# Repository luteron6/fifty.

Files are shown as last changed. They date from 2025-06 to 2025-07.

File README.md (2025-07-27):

# fifty.


This is my take on a minimalist 50% keyboard optimized for commandlines. I created it to solve a problem controlling the computer in my travel van. There's a monitor and computer mounted in the vehicle, but when I'm using it, there's no good spot to put the keyboard. It could go on my lap, but it's huge (~90% keyboard). And there's no spot for a mouse or touchpad. This solves both these problems. At first the goal was to create a 40% keyboard with a touchpad, but it ended up being a 50% keyboard (48 keys) with a round touchpad and right/left mouse buttons. It uses MX Brown switches, a Cirque trackpad, all powered by a Waveshare RP2040-Plus:
<br><br>

It's made to run this keymap:
<br><br>

## CAD
The case is stored in the /CAD folder, both the STL files and the STEP file. Meant to be 3D printed. Everything bolts together with M2 screws and threaded inserts. Also has rubber feet on the bottom.



## PCB
The PCB gerbers and source files are stored in the /PCB folder. I made it in KiCAD:


It needs:
* MX-Style Switches (50)
* SOD-123 Diodes (50)
* Cirque 40mm Trackpad
* 4.7k ohm Resistors (2)
* RP2040-Plus
* Screw-In Stabilizers (1x 2u and 1x 6.25u)

## Code
I made the code in QMK. Source files are in the /Code folder. Still a work in progress, but QMK MSYS can build it, so I put the .uf2 file in the folder. I might still change the layout, but currently it's documented above.

## BOM
| Item | QTY Needed | QTY Purchased | Price | Description | Link |
|---|---|---|---|---|---|
| MX Brown Switches | 50 | 70 | $24.99  | Keyboard Switches! | [link](https://www.amazon.com/Pre-lubed-Switches-Mechanical-Keyboard-Pcs-5pin/dp/B0CKTJLCDB) |
| Cirque Trackpad | 1 | 1 | $27.00  | Trackpad Module | [link](https://shop.beekeeb.com/product/40mm-cirque-glidepoint-circle-trackpad-module-diy-kit-for-split-mechanical-keyboard/) |
| RP2040-Plus | 1 | 1 | $6.99 | Microcontroller | [link](https://www.waveshare.com/rp2040-plus.htm?sku=23503) |
| USB-C Connector | 1 | 1 | $12.99  | USB-C adapter | [link](https://www.amazon.com/Tciogrxp-Magnetic-Connector-Compatible-Thunderbolt/dp/B0DFM1B3DK/) |
| Stabilizers | 1 | 1 | $16.98  | Screw-In Stabilizers | [link](https://www.amazon.com/DUROCK-Stabilizers-Translucent-Keyboard-Mechanical/dp/B0B2RVN19F/) |
| Diodes | 50 | 100 | $6.99 | SOD-123 1N4148W SMD Diodes | [link](https://www.amazon.com/100-Pieces-1N4148W-Switching-High-Speed/dp/B079KJX5J9/) |
| Rubber Feet | 4 | 12 | $5.99 | Rubber Silicone Feet | [link](https://www.amazon.com/Pack-Rubber-Silicone-Feet-Diameter/dp/B0927HC2TD/) |
| Keycaps | 1 | 1 | $14.69  | Low Profile Keycaps! | [link](https://www.amazon.com/XVX-Profile-Keycaps-Keyboard-Mechanical/dp/B0C1B6STX4) |
| Resistors | 2 | 3250 | $7.99 | SMD resistors | [link](https://www.amazon.com/Yobett-3250PCS-Resistor-Tolerance-Resistors/dp/B0BZGQ8136/) |
| PCB (ordered from JLCPCB) | 1 | 5 | $15.00  | | |
| Sales Tax | | | $10.82  | | |
| Shipping | | | $30.00  | JLCPCB Shipping | |
| Shipping | | | $15.00  | beekeeb Shipping | |
| | | | | | |
| TOTAL | | | $195.43 | | |

made with love by a hack clubber

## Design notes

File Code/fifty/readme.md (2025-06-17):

# fifty

fifty

*A short description of the keyboard/project*

* Keyboard Maintainer: [luteron6](https://github.com/luteron6)
* Hardware Supported: *The PCBs, controllers supported*
* Hardware Availability: *Links to where you can find this hardware*

Make example for this keyboard (after setting up your build environment):

    make fifty:default

Flashing example for this keyboard:

    make fifty:default:flash

See the [build environment setup](https://docs.qmk.fm/#/getting_started_build_tools) and the [make instructions](https://docs.qmk.fm/#/getting_started_make_guide) for more information. Brand new to QMK? Start with our [Complete Newbs Guide](https://docs.qmk.fm/#/newbs).

## Bootloader

Enter the bootloader in 3 ways:

* **Bootmagic reset**: Hold down the key at (0,0) in the matrix (usually the top left key or Escape) and plug in the keyboard
* **Physical reset button**: Briefly press the button on the back of the PCB - some may have pads you must short instead
* **Keycode in layout**: Press the key mapped to `QK_BOOT` if it is available

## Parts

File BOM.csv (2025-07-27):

Item | QTY Needed | QTY Purchased | Price | Description | Link
MX Brown Switches | 50 | 65 | $15.00 | Keyboard Switches! | https://www.amazon.com/Gateron-KS-9-Mechanical-Type-Switch/dp/B07X3VLF89/
Cirque Trackpad | 1 | 1 | $27.00 | Trackpad Module | https://shop.beekeeb.com/product/40mm-cirque-glidepoint-circle-trackpad-module-diy-kit-for-split-mechanical-keyboard/
RP2040-Plus | 1 | 1 | $6.99 | Microcontroller | https://www.waveshare.com/rp2040-plus.htm?sku=23503
Stabilizers | 1 | 1 | $16.98 | Screw-In Stabilizers | https://www.amazon.com/DUROCK-Stabilizers-Translucent-Keyboard-Mechanical/dp/B0B2RVN19F/
Diodes | 50 | 100 | $6.99 | SOD-123 1N4148W SMD Diodes | https://www.amazon.com/100-Pieces-1N4148W-Switching-High-Speed/dp/B079KJX5J9/
Rubber Feet | 4 | 12 | $5.99 | Rubber Silicone Feet | https://www.amazon.com/Pack-Rubber-Silicone-Feet-Diameter/dp/B0927HC2TD/
Keycaps | 1 | 1 | $14.69 | Low Profile Keycaps! | https://www.amazon.com/XVX-Profile-Keycaps-Keyboard-Mechanical/dp/B0C1B6STX4
Resistors | 2 | 3250 | $7.99 | SMD resistors | https://www.amazon.com/Yobett-3250PCS-Resistor-Tolerance-Resistors/dp/B0BZGQ8136/
PCB (ordered from JLCPCB) | 1 | 5 | $15.00
Sales Tax |  |  | $10.82
Shipping |  |  | $30.00 | JLCPCB Shipping
Shipping |  |  | $15.00 | beekeeb Shipping
TOTAL |  |  | $172.45
 | 0.357142857

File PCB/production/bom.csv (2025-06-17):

Designator | Footprint | Quantity | Value | LCSC Part #
D1, D10, D11, D12, D13, D14, D15, D16, D17, D18, D19, D2, D20, D21, D22, D23, D24, D25, D26, D27, D28, D29, D3, D30, D31, D32, D33, D34, D35, D36, D37, D38, D39, D4, D40, D42, D43, D44, D45, D46, D5, D51, D52, D53, D54, D55, D6, D7, D8, D9 | D_SOD-123 | 50 | D
J1 | Touchpad | 1 | TOUCHPAD
R1, R2 | 0402 | 2 | Resistor
SW1, SW43, SW44, SW51 | MX_PCB_1.25u | 4 | SW_Push_45deg
SW10, SW11, SW12, SW13, SW14, SW16, SW17, SW18, SW19, SW2, SW20, SW21, SW22, SW23, SW24, SW25, SW26, SW28, SW3, SW30, SW31, SW32, SW33, SW34, SW35, SW36, SW37, SW38, SW39, SW4, SW42, SW45, SW5, SW52, SW53, SW54, SW55, SW6, SW7, SW8, SW9 | MX_PCB_1.00u | 41 | SW_Push_45deg
SW15 | MX_PCB_1.50u | 1 | SW_Push_45deg
SW27, SW40 | MX_PCB_1.75u | 2 | SW_Push_45deg
SW29 | MX_PCB_2.00u | 1 | SW_Push_45deg
SW46 | MX_PCB_6.25u | 1 | SW_Push_45deg
U1 | Raspberry_Pi_Pico | 1 | Raspberry_Pi_RP2040-PLUS

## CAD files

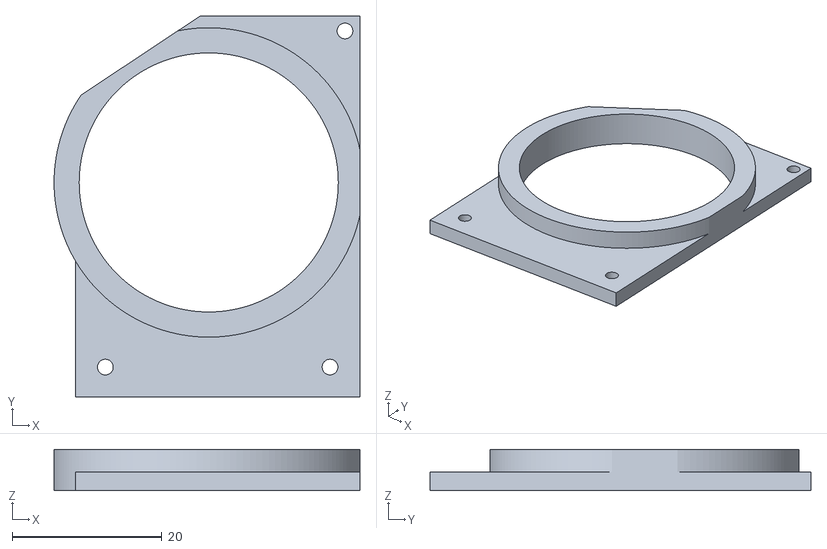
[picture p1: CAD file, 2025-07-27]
CAD/trackpad-holder.stl
40.9 x 50.9 x 5.50

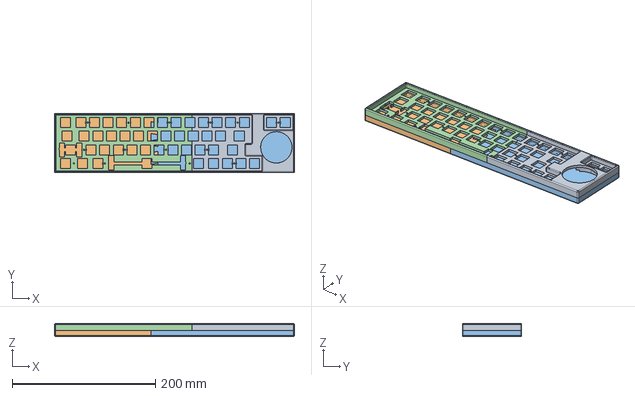
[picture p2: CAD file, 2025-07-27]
CAD/fifty.step
335.4 x 83.0 x 18.1 mm

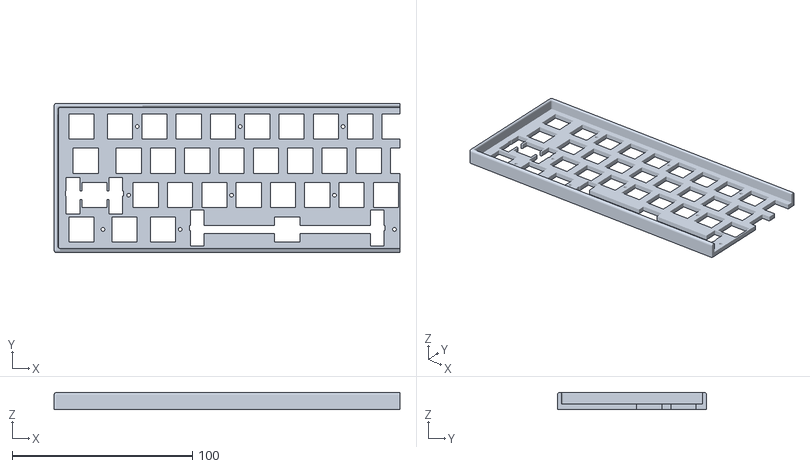
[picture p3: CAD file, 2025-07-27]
CAD/top-left.stl
192.2 x 83.0 x 9.60

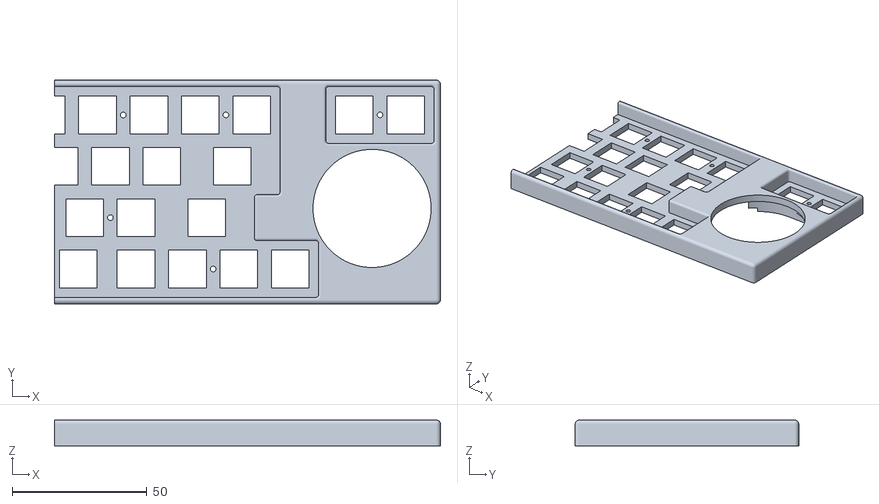
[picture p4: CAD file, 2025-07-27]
CAD/top-right.stl
143.2 x 83.0 x 9.60

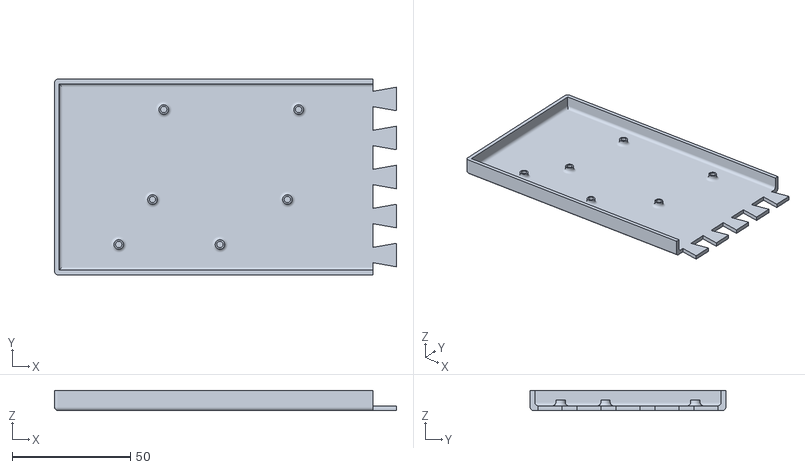
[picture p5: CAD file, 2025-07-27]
CAD/bottom-left.stl
144.8 x 83.0 x 8.50

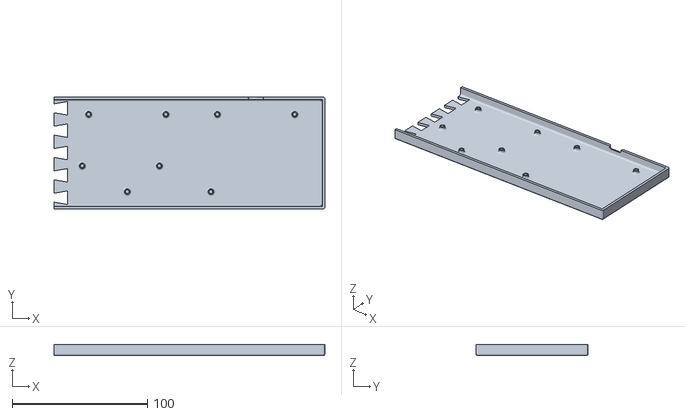
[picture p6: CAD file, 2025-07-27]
CAD/bottom-right.stl
200.4 x 83.0 x 8.50

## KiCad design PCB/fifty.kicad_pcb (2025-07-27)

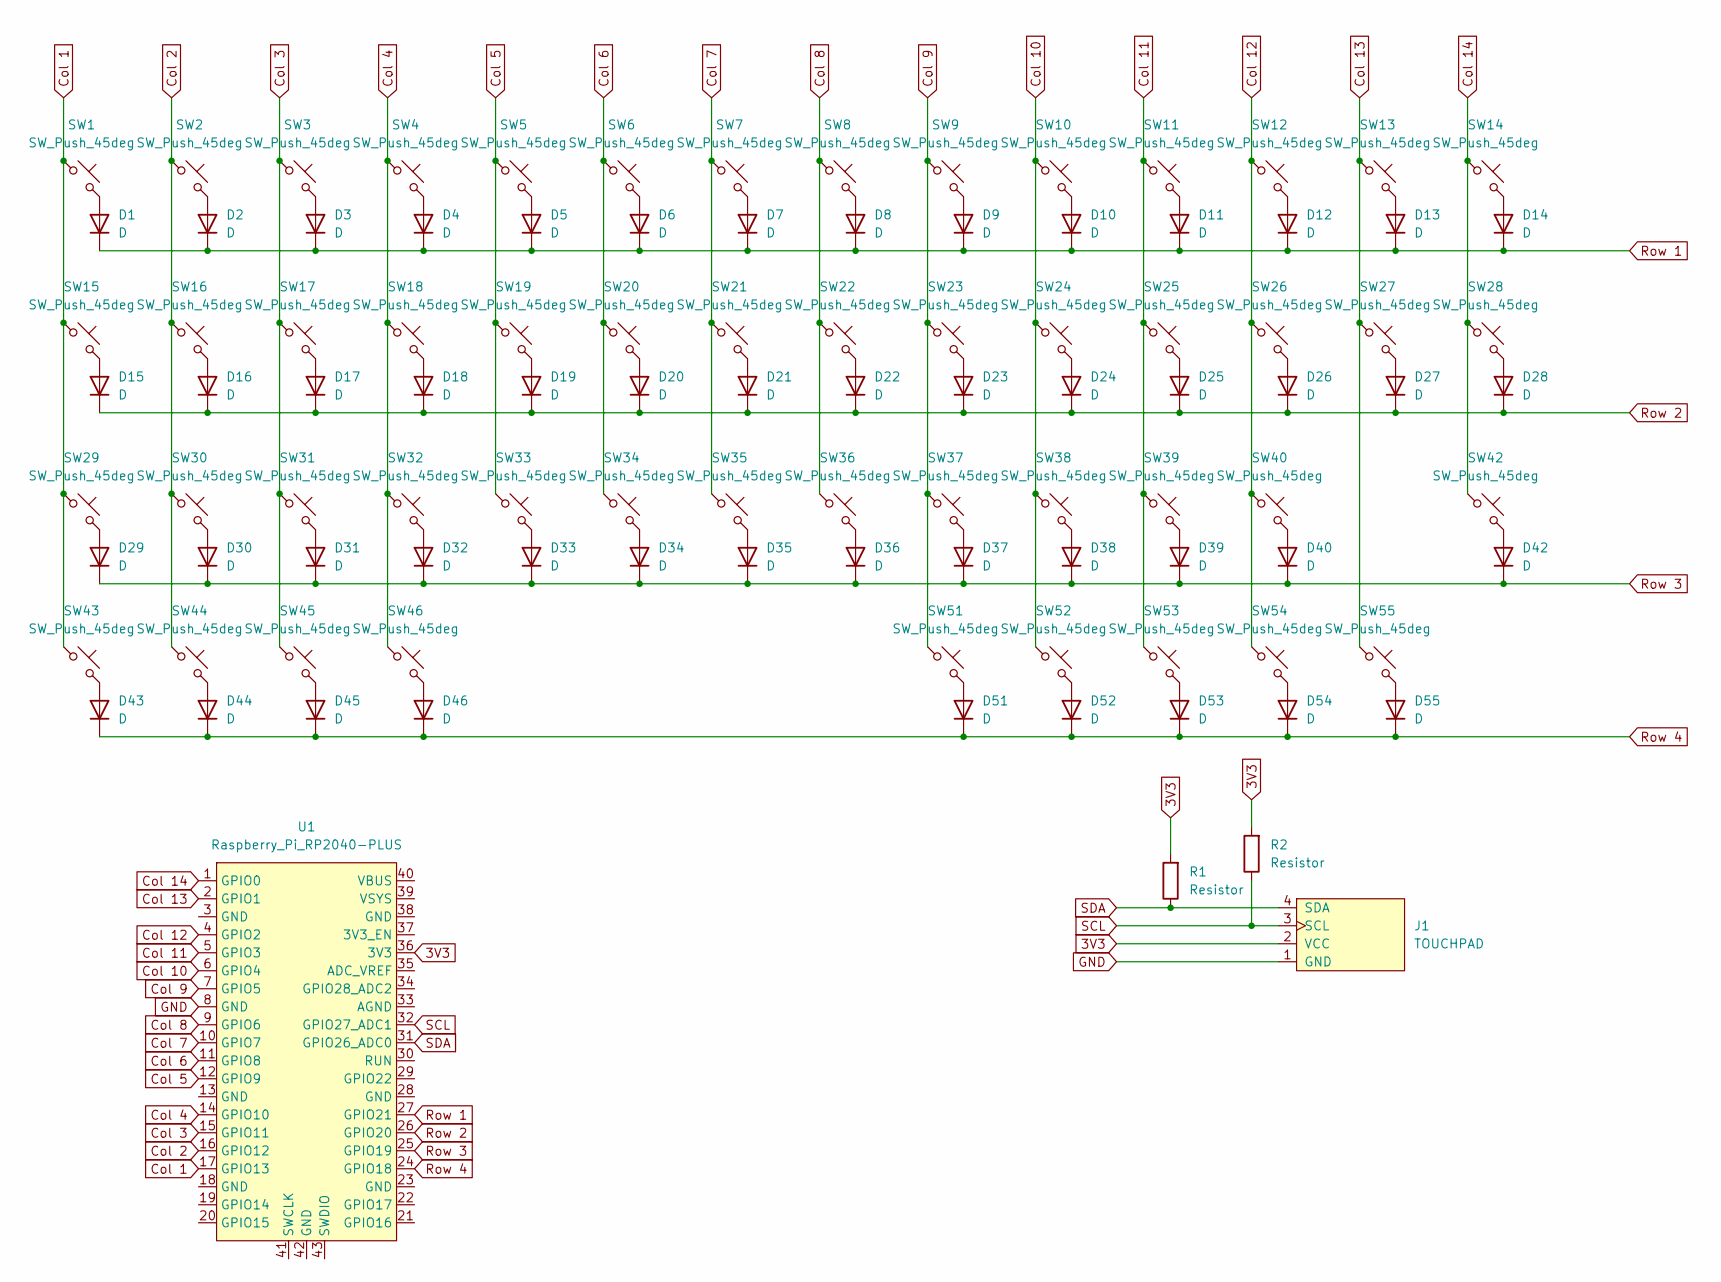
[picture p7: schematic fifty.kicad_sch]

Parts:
D1, D2, D3, D4, D5, D6, D7, D8, D9, D10, D11, D12, D13, D14, D15, D16, D17, D18, D19, D20, D21, D22, D23, D24, D25, D26, D27, D28, D29, D30, D31, D32, D33, D34, D35, D36, D37, D38, D39, D40, D42, D43, D44, D45, D46, D51, D52, D53, D54, D55: D; D_SOD-123
J1: TOUCHPAD; Touchpad
R1, R2: Resistor; R_0402_1005Metric
SW1, SW43, SW44, SW51: SW_Push_45deg; MX_PCB_1.25u
SW2, SW3, SW4, SW5, SW6, SW7, SW8, SW9, SW10, SW11, SW12, SW13, SW14, SW16, SW17, SW18, SW19, SW20, SW21, SW22, SW23, SW24, SW25, SW26, SW28, SW30, SW31, SW32, SW33, SW34, SW35, SW36, SW37, SW38, SW39, SW42, SW45, SW52, SW53, SW54, SW55: SW_Push_45deg; MX_PCB_1.00u
SW15: SW_Push_45deg; MX_PCB_1.50u
SW27, SW40: SW_Push_45deg; MX_PCB_1.75u
SW29: SW_Push_45deg; MX_PCB_2.00u
SW46: SW_Push_45deg; MX_PCB_6.25u
U1: Raspberry_Pi_RP2040-PLUS; Raspberry_Pi_Pico

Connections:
3V3: J1.2 (VCC), R1.2, R2.2, U1.36 (3V3)
Col 1: SW1.1, SW15.1, SW29.1, SW43.1, U1.17 (GPIO13)
Col 2: SW2.1, SW16.1, SW30.1, SW44.1, U1.16 (GPIO12)
Col 3: SW3.1, SW17.1, SW31.1, SW45.1, U1.15 (GPIO11)
Col 4: SW4.1, SW18.1, SW32.1, SW46.1, U1.14 (GPIO10)
Col 5: SW5.1, SW19.1, SW33.1, U1.12 (GPIO9)
Col 6: SW6.1, SW20.1, SW34.1, U1.11 (GPIO8)
Col 7: SW7.1, SW21.1, SW35.1, U1.10 (GPIO7)
Col 8: SW8.1, SW22.1, SW36.1, U1.9 (GPIO6)
Col 9: SW9.1, SW23.1, SW37.1, SW51.1, U1.7 (GPIO5)
Col 10: SW10.1, SW24.1, SW38.1, SW52.1, U1.6 (GPIO4)
Col 11: SW11.1, SW25.1, SW39.1, SW53.1, U1.5 (GPIO3)
Col 12: SW12.1, SW26.1, SW40.1, SW54.1, U1.4 (GPIO2)
Col 13: SW13.1, SW27.1, SW55.1, U1.2 (GPIO1)
Col 14: SW14.1, SW28.1, SW42.1, U1.1 (GPIO0)
GND: J1.1 (GND), U1.8 (GND)
unnamed: D1.2 (A), SW1.2
unnamed: D2.2 (A), SW2.2
unnamed: D3.2 (A), SW3.2
unnamed: D4.2 (A), SW4.2
unnamed: D5.2 (A), SW5.2
unnamed: D6.2 (A), SW6.2
unnamed: D7.2 (A), SW7.2
unnamed: D8.2 (A), SW8.2
unnamed: D9.2 (A), SW9.2
unnamed: D10.2 (A), SW10.2
unnamed: D11.2 (A), SW11.2
unnamed: D12.2 (A), SW12.2
unnamed: D13.2 (A), SW13.2
unnamed: D14.2 (A), SW14.2
unnamed: D15.2 (A), SW15.2
unnamed: D16.2 (A), SW16.2
unnamed: D17.2 (A), SW17.2
unnamed: D18.2 (A), SW18.2
unnamed: D19.2 (A), SW19.2
unnamed: D20.2 (A), SW20.2
unnamed: D21.2 (A), SW21.2
unnamed: D22.2 (A), SW22.2
unnamed: D23.2 (A), SW23.2
unnamed: D24.2 (A), SW24.2
unnamed: D25.2 (A), SW25.2
unnamed: D26.2 (A), SW26.2
unnamed: D27.2 (A), SW27.2
unnamed: D28.2 (A), SW28.2
unnamed: D29.2 (A), SW29.2
unnamed: D30.2 (A), SW30.2
unnamed: D31.2 (A), SW31.2
unnamed: D32.2 (A), SW32.2
unnamed: D33.2 (A), SW33.2
unnamed: D34.2 (A), SW34.2
unnamed: D35.2 (A), SW35.2
unnamed: D36.2 (A), SW36.2
unnamed: D37.2 (A), SW37.2
unnamed: D38.2 (A), SW38.2
unnamed: D39.2 (A), SW39.2
unnamed: D40.2 (A), SW40.2
unnamed: D42.2 (A), SW42.2
unnamed: D43.2 (A), SW43.2
unnamed: D44.2 (A), SW44.2
unnamed: D45.2 (A), SW45.2
unnamed: D46.2 (A), SW46.2
unnamed: D51.2 (A), SW51.2
unnamed: D52.2 (A), SW52.2
unnamed: D53.2 (A), SW53.2
unnamed: D54.2 (A), SW54.2
unnamed: D55.2 (A), SW55.2
Row 1: D1.1 (K), D2.1 (K), D3.1 (K), D4.1 (K), D5.1 (K), D6.1 (K), D7.1 (K), D8.1 (K), D9.1 (K), D10.1 (K), D11.1 (K), D12.1 (K), D13.1 (K), D14.1 (K), U1.27 (GPIO21)
Row 2: D15.1 (K), D16.1 (K), D17.1 (K), D18.1 (K), D19.1 (K), D20.1 (K), D21.1 (K), D22.1 (K), D23.1 (K), D24.1 (K), D25.1 (K), D26.1 (K), D27.1 (K), D28.1 (K), U1.26 (GPIO20)
Row 3: D29.1 (K), D30.1 (K), D31.1 (K), D32.1 (K), D33.1 (K), D34.1 (K), D35.1 (K), D36.1 (K), D37.1 (K), D38.1 (K), D39.1 (K), D40.1 (K), D42.1 (K), U1.25 (GPIO19)
Row 4: D43.1 (K), D44.1 (K), D45.1 (K), D46.1 (K), D51.1 (K), D52.1 (K), D53.1 (K), D54.1 (K), D55.1 (K), U1.24 (GPIO18)
SCL: J1.3 (SCL), R2.1, U1.32 (GPIO27_ADC1)
SDA: J1.4 (SDA), R1.1, U1.31 (GPIO26_ADC0)

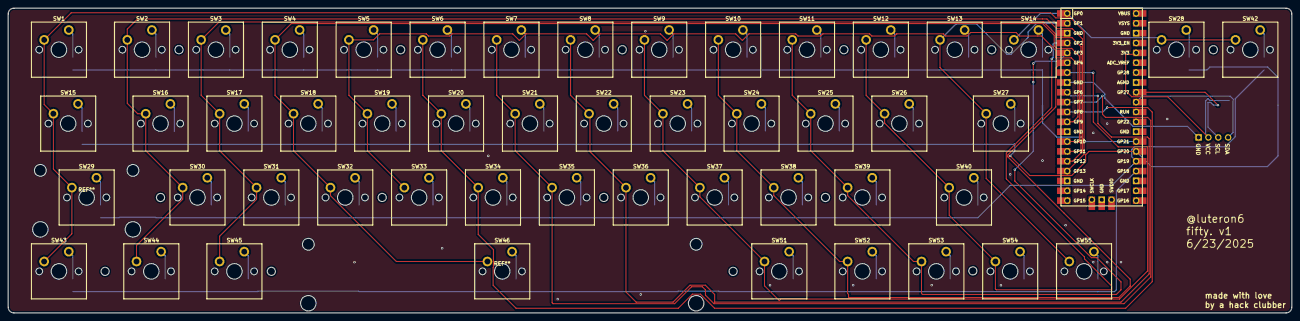
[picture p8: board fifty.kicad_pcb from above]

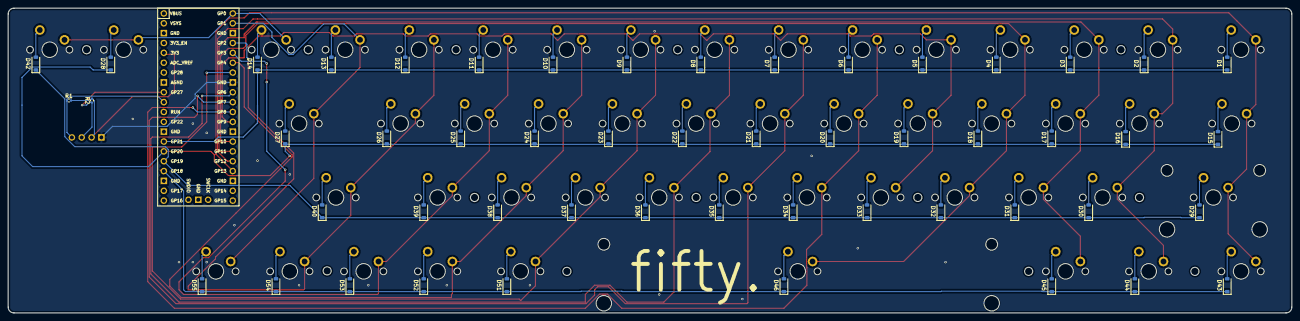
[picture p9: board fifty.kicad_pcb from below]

Board: 2 copper layers, 331.0 x 78.6 mm, 104 parts (52 on the bottom side), 72 nets.

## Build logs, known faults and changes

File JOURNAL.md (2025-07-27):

---
title: "fifty."
author: "@luteron6"
description: "The minimalist 50% keyboard optimized for commandlines!"
created_at: "2025-06-02"
---

# fifty.
Made by: @luteron6

Total hours so far: 33

Estimated Cost: $170

My family has a travel van that has a Raspberry Pi in it. The problem is, it's hard to lug a large (I think it's ~90-100%) keyboard around. So I end VNC'ing in and trying to type on my phone. But it's hard to type special characters, and it's just too small. So here's my solution: a 50% keyboard optimized for commandlines!

## Day 1 - 6/2/2025 - 9:29 PM (1 Hour)
Brainstorming. I've been doing some research about minimalist keyboards over the past couple days, and here's some goals I would like to accomplish:
* I would like my keyboard to be around 40% (about 40 keys).
* I like the borderless-ness of the Vortex Vibe keyboard (below):
<br><br><br>
* I also need to be able to type commandline symbols (~, |, \, {, etc.)
* It would be cool to have dual-legend keys:
<br><br><br>
* It needs to be portable.
* It either runs off of bluetooth and a battery, or just a USB-C port. I know magnetic-USB-C thingies exist, so I might just go with one of those for easy connection/disconnection. The main point is to use it in the van.
<br><br><br>

I also created this repository just now, and added it to Highway's submissions.yml file.

## Day 2 - 6/4/2025 - 6:51 PM (1 Hour)
Ok. Here's what I'm going to do:
* MX switches (because I've used them before)
* Microcontroller: Waveshare RP2040-Zero (I really want an RP2040 with USB-C, but they won't let me get an Orpheus Pico). I'll do without a battery and bluetooth.
* Blank keycaps, or maybe at least the alphabet ones with legends.
* Here's what I was thinking for my layout:
<br><br>

## Day 3 - 6/13/2025 - 2:30 PM (6 Hours)
OK! That took way too long. Here's a summary of what I did:
* I found the MX switches I want to use: [MX Browns](https://www.amazon.com/Glorious-PC-Gaming-Race-Switches/dp/B0716ZNZ1P/) It's a 120 pack, but they're only ~29 cents each!
* I also found the touchpad I want to use. It's a [Cirque GlidePoint 40mm Trackpad](https://shop.beekeeb.com/product/40mm-cirque-glidepoint-circle-trackpad-module-diy-kit-for-split-mechanical-keyboard/). It communicates over I2C, so it connects just like a 0.96" OLED display.
* I finalized my layout! At least the number of keys. It has 48 keys (plus right and left mouse buttons). So technically it's closer to a 50% keyboard. Here's my [KLE](https://www.keyboard-layout-editor.com/##@_css=%2F@font-face%20%7B%0D%0A%20%20font-family%2F:%20'Zain'%2F%3B%0D%0A%20%20src%2F:%20url('https%2F:%2F%2F%2F%2Fraw.githubusercontent.com%2F%2Fgoogle%2F%2Ffonts%2F%2Fmain%2F%2Fofl%2F%2Fzain%2F%2FZain-Regular.ttf')%20format('truetype')%2F%3B%0D%0A%20%20font-style%2F:%20normal%2F%3B%0D%0A%20%20font-weight%2F:%20400%2F%3B%0D%0A%7D%0D%0A%0D%0A.keylabel0,%20.keylabel1,%20.keylabel2,%20.keylabel3,%20.keylabel4,%20.keylabel5,%20.keylabel6,%20.keylabel7,%20.keylabel8,%20.keylabel9,%20.keylabel010,%20.keylabel11,%20.keylabel12%7B%0D%0A%20%20font-family%2F:%20'Zain',%20sans-serif%2F%3B%0D%0A%20%20font-size%2F:%2016px%2F%3B%0D%0A%7D%3B&@_w:1.25%3B&=Esc%0A~%0A%0A%7C&=Q%0A%0A%0A!&=W%0A%0A%0A%2F@&=E%0A%0A%0A%23&=R%0A%0A%0A$&=T%0A%0A%0A%25&=Y%0A%0A%0A%5E&=U%0A%0A%0A%2F&&=I%0A%0A%0A*&=O%0A%0A%0A(&=P%0A%0A%0A)&=%7B%0A%5B&=%7D%0A%5D&=Back%3Cbr%3ESpace&_x:1&a:7%3B&=&=%3B&@_a:4&w:1.5%3B&=Tab&=A%0A%0A%0A1&=S%0A%0A%0A2&=D%0A%0A%0A3&_n:true%3B&=F%0A%0A%0A4&=G%0A%0A%0A5&=H%0A%0A%0A6&_n:true%3B&=J%0A%0A%0A7&=K%0A%0A%0A8&=L%0A%0A%0A9&=%2F:%0A%2F%3B%0A%0A0&=%22%0A'%0A%0A%60&_w:1.75%3B&=Enter%3B&@_w:2%3B&=Shift&=Z%0A%0A%0A-&=X%0A%0A%0A%2F_&=C%0A%0A%0A%2F=&=V%0A%0A%0A+&=B&=N&=M&=%3C%0A,&=%3E%0A.&=%3F%0A%2F%2F%0A%0A%5C&_w:1.75%3B&=Shift%3B&@_w:1.25%3B&=CTRL&_a:7&w:1.25%3B&=%3Ci%20class%2F='fa%20fa-windows'%3E%3C%2F%2Fi%3E&_a:4%3B&=Alt&_a:7&w:6.25%3B&=&_a:4&w:1.25%3B&=Fn&_a:7%3B&=%3Ci%20class%2F='fa%20fa-angle-left'%3E%3C%2F%2Fi%3E&=%3Ci%20class%2F='fa%20fa-angle-down'%3E%3C%2F%2Fi%3E&=%3Ci%20class%2F='fa%20fa-angle-up'%3E%3C%2F%2Fi%3E&=%3Ci%20class%2F='fa%20fa-angle-right'%3E%3C%2F%2Fi%3E) layout. It's also pictured below:
<br><br>thumbnail_IMG_2734<br>
* I put it all into KiCad, drew up the schematic, laid out the PCB, and routed it all: <br><br>



*Ignore the OLED screen, I just copied the footprint over and will be using it as a header for the touchpad.

* I didn't have enough pins on the RP2040-Zero for the matrix, so I switched to the [RP2040-Plus](https://www.waveshare.com/wiki/RP2040-Plus#Pinout_Definition) board also by Waveshare.

That's basically what I did! Also I now have a rough BOM:
* [MX Brown Switches (50)](https://www.amazon.com/Glorious-PC-Gaming-Race-Switches/dp/B0716ZNZ1P/): $34.99
* [Trackpad](https://shop.beekeeb.com/product/40mm-cirque-glidepoint-circle-trackpad-module-diy-kit-for-split-mechanical-keyboard/): $27.00
* [RP2040-Plus](https://www.waveshare.com/rp2040-plus.htm?sku=23503): $6.99
* PCB (from JLCPCB, approximately): $15.00
* [Magnetic USB-C Connector](https://www.amazon.com/Magnetic-DuHeSin-Straight-Transfer-Thunderbolt/dp/B0BMX53FF9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): $20.89
* Misc. (resistors, etc.): $5.00
* Total: $109.87

## Day 3 - 6/13/2025 - 6:59 PM (3 Hours)
I forgot to mention regarding the circuit board - it's a 14x4 matrix (14 columns, 4 rows). I also edited the right side of my PCB so there's a touchpad circle:
<br><br><br>

Here's what I have on my case: 




## Day 4 - 6/14/2025 - 8:07 PM (2 Hours)
Just finished working on my case more. It took me a while to find the docs for the touchpad, but I found these with mounting suggestions: [here](https://www.dropbox.com/scl/fi/fl600un1qv1cupbfjng95/GP-DS-170409-TM035035-SPI-I2C-PINN-Trackpad-Spec.pdf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).
Here's what I have on the touchpad:<br>

I also saw Scotto Keebs' video on making a case, and he put edges around his case, so I also did that ^. I need to keep working on the case, and get started on QMK.

I need to add these things to the BOM:
* [Stabilizers](https://www.amazon.com/DUROCK-Stabilizers-Translucent-Keyboard-Mechanical/dp/B0B2RVN19F/): $16.98
* [SMD Diodes](https://www.amazon.com/100-Pieces-1N4148W-Switching-High-Speed/dp/B079KJX5J9/): $6.99
* Total: $133.84

## Day 5 - 6/16/2025 - 1:20 PM (5 Hours)
THAT WAS A LOT! Here's a recap of what I did:
I was editing my case, placing keycaps on the switches, and I realized I could raise the spot where the microcontroller is, along with the touchpad:

Then I had an epiphany: Why am I putting the microcontroller on the bottom of the board when I can have it above the PCB? I's a bad idea to have the USB on the bottom, because it's too close to the bottom of the case. So I went back into KiCAD, flipped the RP2040, and re-traced all the traces previously connected to the RP2040. It took me a while to delete the old traces and redo them. Now they look really wonky.

Then I reworked the USB port on the case:

Then I cleaned up my case a little bit more, added some rubber feet, and I think it's done now!







Here's what I need to add to my BOM:
* [Rubber Feet](https://www.amazon.com/Pack-Rubber-Silicone-Feet-Diameter/dp/B0927HC2TD/): $5.99
* [Keycaps](https://www.amazon.com/139keys-Sublimation-switches-Mechanical-Keyboard/dp/B0BR8SMKLS/): $9.99

Here's my whole BOM now:
* [MX Brown Switches (50)](https://www.amazon.com/Pre-lubed-Switches-Mechanical-Keyboard-Pcs-5pin/dp/B0CKTJLCDB): $24.99
* [Trackpad](https://shop.beekeeb.com/product/40mm-cirque-glidepoint-circle-trackpad-module-diy-kit-for-split-mechanical-keyboard/): $27.00
* [RP2040-Plus](https://www.waveshare.com/rp2040-plus.htm?sku=23503): $6.99
* PCB (from JLCPCB, approximately): $15.00
* [Magnetic USB-C Connector](https://www.amazon.com/Tciogrxp-Magnetic-Connector-Compatible-Thunderbolt/dp/B0DFM1B3DK/): $11.99
* [Stabilizers](https://www.amazon.com/DUROCK-Stabilizers-Translucent-Keyboard-Mechanical/dp/B0B2RVN19F/): $16.98
* [SMD Diodes](https://www.amazon.com/100-Pieces-1N4148W-Switching-High-Speed/dp/B079KJX5J9/): $6.99
* [Rubber Feet](https://www.amazon.com/Pack-Rubber-Silicone-Feet-Diameter/dp/B0927HC2TD/): $5.99
* [Keycaps](https://www.amazon.com/139keys-Sublimation-switches-Mechanical-Keyboard/dp/B0BR8SMKLS/): $9.99
* [4.7k Ohm Resistors](https://www.amazon.com/EDGELEC-Resistor-Tolerance-Multiple-Resistance/dp/B07QJB3LGN/): $5.99
* M2 Threaded Inserts: already owned
* TOTAL: $131.91. I'll have to work stuff if I have shipping later.

## Day 6 - 6/17/2025 - 10:36 AM (3 Hours)
I realized I didn't have any way to connect the bottom half of my case to the top half of my case, so I added holes in my plate, PCB, and threaded inserts to the bottom of my case. It took me forever to get the holes lined up to the PCB and the plate, but here it is:

I also added some art to my case and some information, made the code in QMK, and put everything in this Github repo. Will try to submit later today.

## Day 7-9 - 7/26/2025 - 9:57 PM (about 7-9 hours)
OK! I finally got everything a few days ago and had some time to work on my keyboard. My PCB got stuck in customs for a week, so it took forever to get to my house. Anyway, I enjoyed attempting to solder the tiny 0402 resistors for the I2C bus. More on that later. After the 0402s, the SOD-123 diodes were really easy to solder:
<div style="display: flex; gap: 20px;">
  
  
</div>

I also soldered the microcontroller, SMD style:<br>

Later, I realized that on my case, the touchpad dimensions were way off. So I had to redesign the whole touchpad mounting system. Also, my plate is 3mm thick, and I didn't realize that wouldn't be compatible with my screw-in stabilizers. So I had to reprint both halves of my plate to make it work. Even then, I didn't make the cutouts big enough, and I had to use some tools to make the cutout bigger. Here are some pictures:

<div style="display: flex; gap: 20px;">
  
  
  
</div>

So much for those 0402 resistors:<br>

Here's the whole keyboard! I really like how it turned out.


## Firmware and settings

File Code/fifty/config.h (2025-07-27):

#define POINTING_DEVICE_TASK_THROTTLE_MS 1
#define CIRQUE_PINNACLE_I2C
#define CIRQUE_PINNACLE_ADDRESS 0x2A
#define I2C_DRIVER I2CD1
#define I2C1_SDA_PIN GP26
#define I2C1_SCL_PIN GP27
// I2C speed configuration (uncomment one):
//#define I2C1_CLOCK_SPEED 100000  // 100kHz (standard mode)
#define I2C1_CLOCK_SPEED 400000  // 400kHz (fast mode) - default
// #define I2C1_CLOCK_SPEED 1000000 // 1MHz (fast mode plus)
#define CIRQUE_PINNACLE_DIAMETER_MM 40
#define POINTING_DEVICE_INVERT_X
#define POINTING_DEVICE_INVERT_Y
#define POINTING_DEVICE_GESTURES_SCROLL_ENABLE
//#define POINTING_DEVICE_GESTURES_CURSOR_GLIDE_ENABLE
//#define POINTING_DEVICE_GESTURE_SCROLL_DIVISOR_H 8
//#define POINTING_DEVICE_GESTURE_SCROLL_DIVISOR_V 8
#define CIRQUE_PINNACLE_ATTENUATION EXTREG__TRACK_ADCCONFIG__ADC_ATTENUATE_3X

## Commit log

2025-06-15 Added to BOM
2025-06-17 uploaded case STEP file
    [fifty.step]
2025-06-17 Add BOM in CSV format
    [BOM.csv]
2025-07-27 Updated all files since building project
    [BOM.csv, bottom-left.stl, bottom-right.stl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]
